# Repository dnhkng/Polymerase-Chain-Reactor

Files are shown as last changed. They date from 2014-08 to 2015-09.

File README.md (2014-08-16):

Polymerase-Chain-Reactor
========================

An Open Source PCR machine for DIY Recombinant Genetics, and entry to the Hackaday Prize! If you like it, please Skull it at http://hackaday.io/project/1864-%245-Polymerase-Chain-Reactor

This project describes the designs for a remarkably simple but fully functional DNA replicator, based around the Arduino platform, and utilizing just a handful of components. The trick is to use multiple physical process driven by just heat! Heat drives DNA conversion between its single and double strand state; alters the activity of the polymerase to copy DNA; and drives circulation of the reaction medium via convection. So, it's all and heat and geometry, intead of trying to shift temperature as fast and accurately as possible with expensive hardware. 

It uses the Arduino libraries, and the Arduino PID Library by Brett Beauregard.

Eagle schematics and a boards layout files are also included.

The project is GPLv3 licenced

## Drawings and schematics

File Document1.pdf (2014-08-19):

# $5 PCR Machine

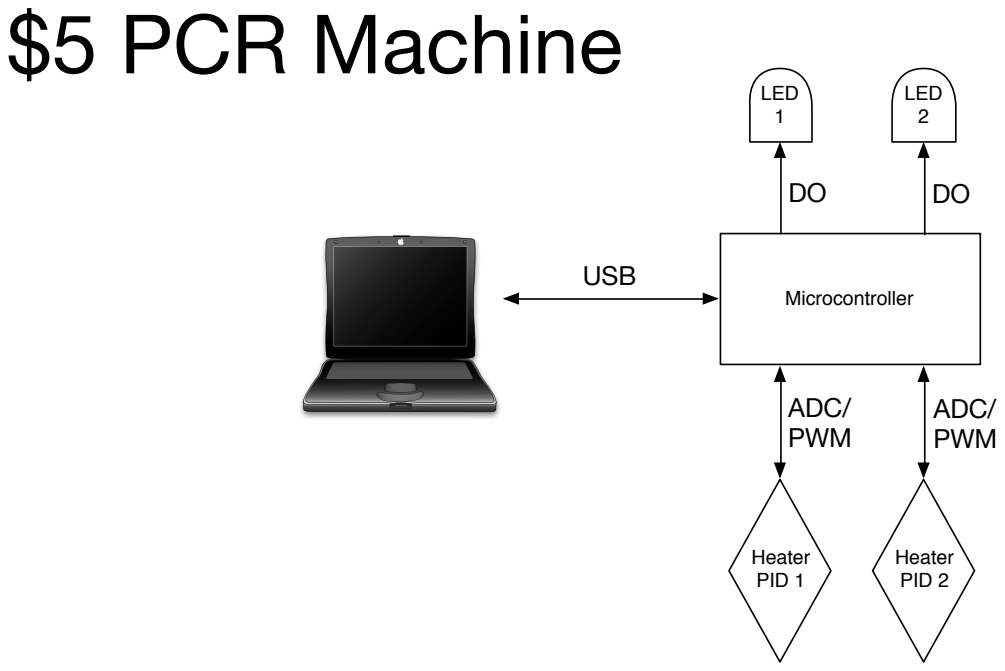
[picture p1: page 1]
Microcontroller; USB; Heater PID 1; Heater PID 2; LED 1; LED 2; ADC/ PWM

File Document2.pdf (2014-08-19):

## CLOUD

# $50 PCR Machine

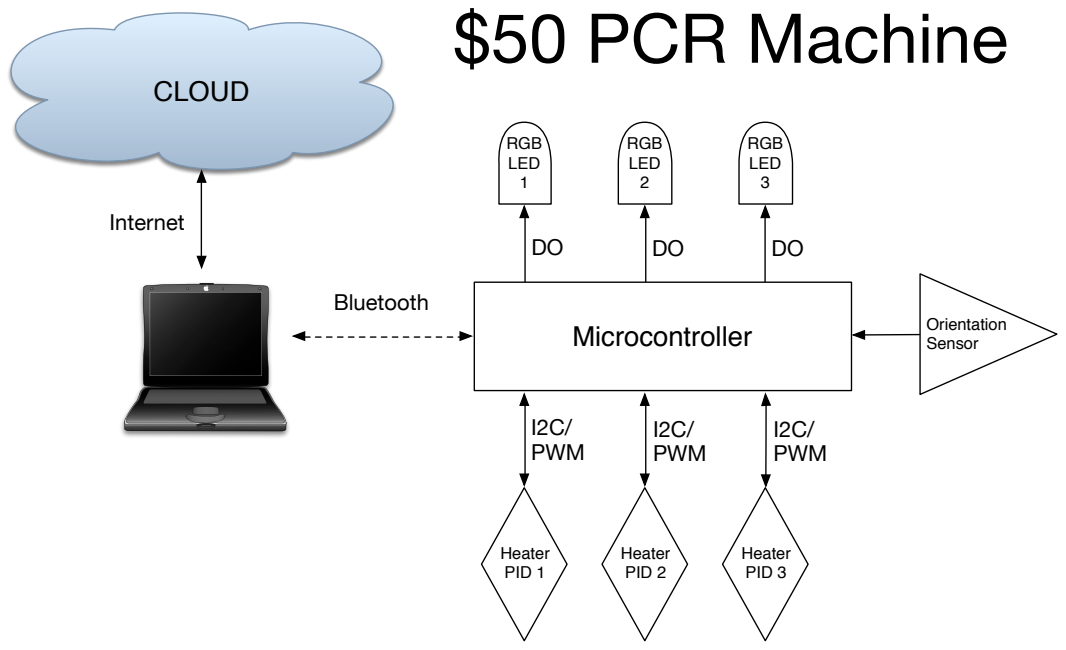
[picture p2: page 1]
Microcontroller; Bluetooth; Internet; Heater PID 1; Heater PID 2; RGB LED 1; I2C/ PWM; Heater PID 3; Orientation Sensor; RGB LED 2; RGB LED 3

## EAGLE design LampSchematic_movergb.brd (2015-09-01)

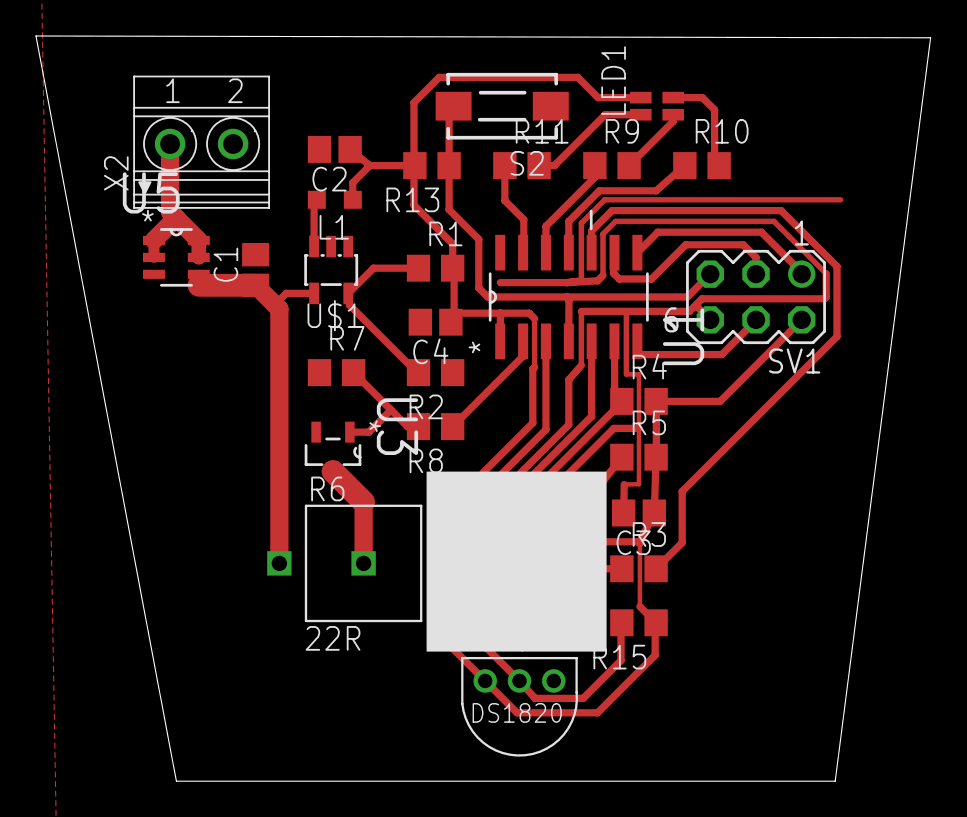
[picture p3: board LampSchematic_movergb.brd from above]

Board: 2 copper layers, 49.7 x 41.4 mm, 29 parts (0 on the bottom side), 24 nets.

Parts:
C1, C3, C4: 0.1uF; C0805
C2: 10uF; C0805
L1: 10uH; L2012C
LED1: GM1WA55311A
R1: 61.9k; R0805
R2: 20k; R0805
R3, R15: 6.8R; R0805
R4, R5: 4.7k; R0805
R6: 22R; 5WRESISTOR
R7: 100k; R0805
R8: 47R; R0805
R9: 330R; R0805
R10, R11: 68R; R0805
R13: 10k; R0805
S2: DTSM-3
SV1: ISP; MA03-2
U1: ATTINY84-20SSU; SOIC127P600X175-14N
U2: VEML6040
U3: PMV20ENR; SOT95P230X110-3N
U5: Si3417DV; SOP95P285X110-6N
U$1: TPS560200; SOT23-5L
U$2: DS1820TO92; DS1820
U$3: UV; GM5BW96385A
X2: 1751248

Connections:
+12V: C1.1, R6.P$2, U5.4, U$1.4
BLUE: R11.1, U1.13
GND: C1.2, C2.2, C3.2, C4.2, R2.1, R7.1, S2.1, SV1.6, U1.14, U2.1, U3.2, U5.3, U$1.2, U$2.GND, U$3.2, X2.2
GREEN: R10.1, U1.11
HEAT: R8.1, U1.2
MISO: SV1.1, U1.8
MOSI: SV1.4, U1.7
unnamed: L1.2, U$1.3
unnamed: R1.1, R2.2, U$1.5
unnamed: R6.P$1, U3.3
unnamed: R7.2, R8.2, U3.1
unnamed: LED1.2, R9.2
unnamed: LED1.3, R10.2
unnamed: LED1.1, R11.2
unnamed: R3.1, U$3.1
unnamed: U5.1, U5.2, U5.5, U5.6, X2.1
RED: R9.1, U1.12
RES: R13.1, S2.2, SV1.5, U1.4
SCK: SV1.3, U1.9
SCLK: R5.1, U1.5, U2.3
SDAT: R4.1, U1.6, U2.2
TEMP: R15.2, U1.3, U$2.DQ
UV: R3.2, U1.10
VCC: C2.1, C3.1, C4.1, L1.1, LED1.4, R1.2, R4.2, R5.2, R13.2, R15.1, SV1.2, U1.1, U2.4, U$2.VDD

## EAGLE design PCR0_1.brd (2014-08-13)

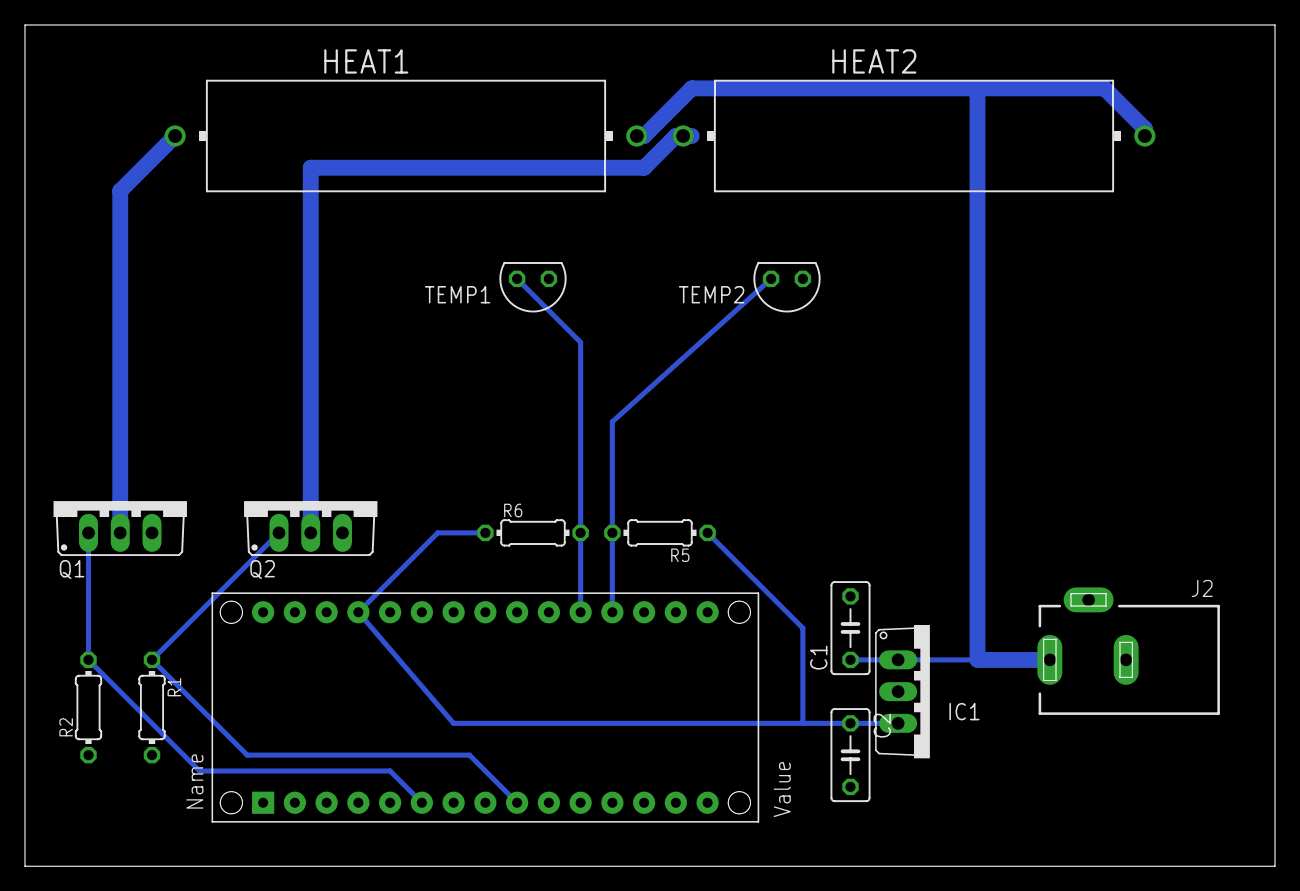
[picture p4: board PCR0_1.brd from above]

Board: 2 copper layers, 100.0 x 67.3 mm, 15 parts (0 on the bottom side), 9 nets.

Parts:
C1, C2: C050-030X075
HEAT1, HEAT2: 10; HPS932
IC1: 7805TV; TO220V
J2: DCJ0303
Q1, Q2: IRF740; TO220BV
R1, R2: 10K; 0204/7
R5, R6: 2K; 0204/7
TEMP1, TEMP2: LM335; TO92H
U$1: PDIP-32

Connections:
+5V: C2.1, IC1.3, R5.1, R6.1, U$1.+5V
GND: C1.2, C2.2, IC1.2, J2.2, J2.3, Q1.S, Q2.S, R1.2, R2.1, TEMP1.1, TEMP2.1, U$1.GND, U$1.GND1
H1: Q1.G, R2.2, U$1.D3
H2: Q2.G, R1.1, U$1.D6
unnamed: HEAT1.1, Q1.D
unnamed: HEAT2.1, Q2.D
T1: R6.2, TEMP1.2, U$1.A6
T2: R5.2, TEMP2.2, U$1.A7
V+: C1.1, HEAT1.2, HEAT2.2, IC1.1, J2.1

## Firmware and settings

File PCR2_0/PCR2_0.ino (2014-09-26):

#include <Wire.h>
#include <PID_v1.h>
#include <SerialCommand.h>

SerialCommand sCmd; 

int SensorA = 0b0011001; // Denaturation
int SensorB = 0b0011010; // Annealing
int SensorC = 0b0011000; // Elongation

int TempReg = 0b00000101;

int HeaterPinA = 5; // Denaturaion
int HeaterPinB = 3; // Annealing
int HeaterPinC = 6; // Elongation

double TargetA = 1.0;
double TargetB = 1.0;
double TargetC = 1.0;

double InputA, InputB, InputC;
double OutputA, OutputB, OutputC;

double P = 100.0;
double I = 0.0;
double D = 0.0;

boolean stream = LOW;

PID HeaterA(&InputA, &OutputA, &TargetA, 100,0,0, DIRECT);
PID HeaterB(&InputB, &OutputB, &TargetB, 100,0,0, DIRECT);
PID HeaterC(&InputC, &OutputC, &TargetC, 100,0,0, DIRECT);

void setup() {
  Wire.begin();        // join i2c bus (address optional for master)
  Serial.begin(38400);
  
  pinMode(HeaterPinA, OUTPUT);
  pinMode(HeaterPinB, OUTPUT);
  pinMode(HeaterPinC, OUTPUT);
  
  HeaterA.SetMode(AUTOMATIC);
  HeaterB.SetMode(AUTOMATIC);
  HeaterC.SetMode(AUTOMATIC);
  
  HeaterA.SetTunings(P,I,D);
  HeaterB.SetTunings(P,I,D);
  HeaterC.SetTunings(P,I,D);
  
  // Setup callbacks for SerialCommand commands
  sCmd.addCommand("SETPID",   setPID);     // Set the PID values for a heating element
  sCmd.addCommand("SETTEMP",  setTEMP);    // Set the target temperature for a heating element
  sCmd.addCommand("GETPID",   getPID);     // Return the PID values for a heating element
  sCmd.addCommand("GETTARGET", getTARGET); // Return the temperature of a heating element  
  sCmd.addCommand("GETTEMP",  getTEMP);    // Return the temperature of a heating element
  sCmd.addCommand("STARTSTREAM",  streamSTART);  // turns on and off continuous temperature reporting
  sCmd.addCommand("STOPSTREAM",  streamSTOP);  // turns on and off continuous temperature reporting
  sCmd.addCommand("RESET",  resetTWI);  // turns on and off continuous temperature reporting
  sCmd.addCommand("OFF",  powerDown);      // turns off all heaters by setting target temp to zero
  sCmd.setDefaultHandler(unrecognized);    // Handler for command that isn't matched  (says "Unrecognized Command?")
  
  // Sets temperature sensors for measurement mode
  Wire.beginTransmission(SensorA); // transmit to I2C
  Wire.write(TempReg);              // sends one byte.   
  Wire.endTransmission();    // stop transmitting
  Wire.beginTransmission(SensorB); // transmit to I2C
  Wire.write(TempReg);              // sends one byte.   
  Wire.endTransmission();    // stop transmitting
  Wire.beginTransmission(SensorC); // transmit to I2C
  Wire.write(TempReg);              // sends one byte.   
  Wire.endTransmission();    // stop transmitting
  
  Serial.println("PCR Device Ready");
}


float temperature(int I2C_address) {
  Wire.requestFrom(I2C_address, 2);    // request 2 bytes from address. Because sensor produces 9 bit
  int ambientUpper = 0;
  int ambientLower = 0;
  
  while(Wire.available()) {   // slave may send less than requested
    ambientUpper = Wire.read(); // receive a byte as integer
    ambientLower = Wire.read(); // receive a byte as integer Can change resolution of by chaning 2nd and 3rd bit of the register pointers.
  }  
  
  int a = ambientUpper << 6; // bitshift 6 to the left to allow for 9bit data from temp sensor
  int b = ambientLower >> 2; //bitshift 7 to the right to allow for 9 bit data from temp sensor.
  int tempRaw = a|b;  // define int rawtemp as the combination of integer a and b. We now have 9 bits of data. 
  float dec = 0.0;
  float power = 0.25;
  int mask; 
  int weight;
  
  for (mask = 1; mask<256; mask <<= 1) {
    if (tempRaw & mask) {
      weight = 1;     
    }
    else {
      weight = 0;     
    }  
    dec = dec + (power * weight);
    power = power * 2; 
 }
  return dec;
}  


void setPID() {
  char *arg;
  float p;
  float i;
  float d;
  boolean malformed = LOW;

  arg = sCmd.next();
  if (arg != NULL) {
    if (atof(arg) > 0 && atof(arg) < 300) {
      p = atof(arg);
    }
    else {
      malformed = HIGH;
    }  
  }    
  else {
    malformed = HIGH;
  } 
  
  arg = sCmd.next();
  if (arg != NULL) {
    if (atof(arg) > 0 && atof(arg) < 300) {
      i = atof(arg);
    }
    else {
      malformed = HIGH;
    }
  }      
  else {
    malformed = HIGH;
  } 
  
  arg = sCmd.next();
  if (arg != NULL) {
    if (atof(arg) > 0 && atof(arg) < 300) {
      d = atof(arg);
    }
    else {
      malformed = HIGH;
    }  
  }  
  else {
    malformed = HIGH;
  }  
  
  arg = sCmd.next();
  if (arg != NULL) {
    malformed = HIGH;
  }  
  
  if (!malformed) {
    HeaterA.SetTunings(p,i,d);
    HeaterB.SetTunings(p,i,d);
    HeaterC.SetTunings(p,i,d);
    Serial.print("PID Values: ");
    Serial.print(p);
    Serial.print(", ");
    Serial.print(i);
    Serial.print(", ");
    Serial.println(d);
  }
  else {
    Serial.println("Unrecognized Command");
  }  
}

void setTEMP() {
  char *arg;
  float tempA;
  float tempB;
  float tempC;
  boolean malformed = LOW;
  

  arg = sCmd.next();
  if (arg != NULL) {
    if (atof(arg) > 0 && atof(arg) < 100) {
      tempA = atof(arg);
    }
    else {
      malformed = HIGH;
    }  
  }    
  else {
    malformed = HIGH;
  } 
  
  arg = sCmd.next();
  if (arg != NULL) {
    if (atof(arg) > 0 && atof(arg) < 100) {
      tempB = atof(arg);
    }
    else {
      malformed = HIGH;
    }  
  }    
  else {
    malformed = HIGH;
  } 
  
  arg = sCmd.next();
  if (arg != NULL) {
    if (atof(arg) > 0 && atof(arg) < 100) {
      tempC = atof(arg);
    }
    else {
      malformed = HIGH;
    }  
  }    
  else {
    malformed = HIGH;
  }   
  
  arg = sCmd.next();
  if (arg != NULL) {
    malformed = HIGH;
  }  
  
  if (!malformed) {
    TargetA = tempA;
    TargetB = tempB;
    TargetC = tempC;
    Serial.print("Temperature Target Values: ");
    Serial.print(TargetA);
    Serial.print(", B:");
    Serial.print(TargetB);
    Serial.print(", C:");
    Serial.println(TargetC);
  }
  else {
    Serial.println("Unrecognized Command");
  }  
}


void getPID() {
  Serial.print("PID Values: P:");
  Serial.print(HeaterA.GetKp());
  Serial.print(", I:");
  Serial.print(HeaterA.GetKi());
  Serial.print(", D:");
  Serial.println(HeaterA.GetKd());
}


void getTARGET() {
  Serial.print("Temperature Target Values: A:");
  Serial.print(TargetA);
  Serial.print(", B:");
  Serial.print(TargetB);
  Serial.print(", C:");
  Serial.println(TargetC);
}

void getTEMP() {
  float tempA = temperature(SensorA);
  float tempB = temperature(SensorB);
  float tempC = temperature(SensorC);
  Serial.print("Temperature Values: A:");  
  Serial.print(tempA);
  Serial.print(", B:");
  Serial.print(tempB);
  Serial.print(", C:");
  Serial.println(tempC);

}  

void streamSTART() {
  stream = HIGH;
  Serial.println("Stream Started");
}

void streamSTOP() {
  stream = LOW;
  Serial.println("Stream Stopped");
}


void powerDown() {
  TargetA = 1.0;
  TargetB = 1.0;
  TargetC = 1.0;
  Serial.print("TEMP Targets: A:");
  Serial.print(TargetA);
  Serial.print(", B:");
  Serial.print(TargetB);
  Serial.print(", C:");
  Serial.println(TargetC);
}  


void resetTWI() {
  // Sets temperature sensors for measurement mode
  Wire.beginTransmission(SensorA); // transmit to I2C
  Wire.write(TempReg);              // sends one byte.   
  Wire.endTransmission();    // stop transmitting
  Wire.beginTransmission(SensorB); // transmit to I2C
  Wire.write(TempReg);              // sends one byte.   
  Wire.endTransmission();    // stop transmitting
  Wire.beginTransmission(SensorC); // transmit to I2C
  Wire.write(TempReg);              // sends one byte.   
  Wire.endTransmission();    // stop transmitting
  Serial.print("TWI Temperature Sensors Reset");
}  
  
void unrecognized(const char *command) {
  Serial.println("Unrecognized Command");
}

void loop() {
  sCmd.readSerial(); 

  InputA = temperature(SensorA);
  HeaterA.Compute();
  analogWrite(HeaterPinA,OutputA);
  
  InputB = temperature(SensorB);
  HeaterB.Compute();
  analogWrite(HeaterPinB,OutputB);  
  
  InputC = temperature(SensorC);
  HeaterC.Compute();
  analogWrite(HeaterPinC,OutputC);  

  if (stream){
    Serial.print("DATA ");
    Serial.print(InputA);
    Serial.print(' ');
    Serial.print(InputB);
    Serial.print(' ');
    Serial.print(InputC);
    Serial.print(' ');
    Serial.print(OutputA);
    Serial.print(' ');
    Serial.print(OutputB);
    Serial.print(' ');
    Serial.println(OutputC); 
  }
  
  delay(500);
}

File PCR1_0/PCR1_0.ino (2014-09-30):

/********************************************************
 * Polymerase Chair Reactor v0.2.1
 * This Library is licensed under a GPLv3 License
 * Uses the Arduino Nano
 * Requires the Arduino PID Library by Brett Beauregard
 ********************************************************/

#include <PID_v1.h>
#include <HIDSerial.h>

HIDSerial serial;

//Define Variables we'll be connecting to
double Setpoint1 = 95;
double Setpoint2 = 72;
double Input1, Output1, Input2, Output2;
float ADC1 = 0, ADC2 = 0, temp1 = 0, temp2=0;
unsigned long serialTime;
int led = 0, Probe1 = 1, Probe2 = 0, PWM1 = 6, PWM2 = 5;
boolean state = LOW;

//Specify the links and initial tuning parameters
PID myPID1(&Input1, &Output1, &Setpoint1, 80,0,0, DIRECT);
PID myPID2(&Input2, &Output2, &Setpoint2, 80,0,0, DIRECT);

void setup()
{
  //initialize the variables we're linked to
  pinMode(PWM1, OUTPUT);
  pinMode(PWM2, OUTPUT);
  pinMode(led, OUTPUT);
  digitalWrite(led, HIGH); 

  ADC1 = analogRead(Probe1);
  ADC2 = analogRead(Probe2);  

  serial.begin();
  //turn the PID on
  myPID1.SetMode(AUTOMATIC);
  myPID2.SetMode(AUTOMATIC);
}

void loop()
{
  serial.poll();
  
  
  ADC1 = analogRead(Probe1);
  ADC2 = analogRead(Probe2);
  

  temp1 = ADC1 * -0.3059 + 198.39; //Calculate these contants from a linear fit with a thermometer
  temp2 = ADC2 * -0.3059 + 198.39;
  
  Input1 = temp1;
  Input2 = temp2;
  
  myPID1.Compute();
  myPID2.Compute();
  
  analogWrite(PWM1,Output1);
  analogWrite(PWM2,Output2);
  
  if(millis()>serialTime)
  {
    //SerialReceive();
    SerialSend();
    //serial.println("Hello World!");
    //serial.println(raw);
    serialTime+=1000;
    
    if(state) {
      state = LOW;
      digitalWrite(led, LOW);
    }  
    else {
      state = HIGH;
      digitalWrite(led, HIGH);
    }
    delay(30); // reduces ADC interferrence
  }
 
}

void SerialSend()
{
  serial.print(ADC1);
  serial.print(" ");
  serial.print(ADC2);
  serial.print(" ");
  serial.print(temp1);
  serial.print(" ");  
  serial.print(temp2);
  serial.print(" ");
  serial.print(Output1);
  serial.print(" ");
  serial.println(Output2); 
}

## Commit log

2014-08-12 First Upload
    Arduino 1.0.5 code for the Polymerase Chain Reactor, and entry in the
    Hackaday Prize
2014-08-13 Schematics and PCB designs
    A simple single-sided board for the Arduino Nano based device.
    [v02.brd, v02.sch]
2014-09-26 The second, more sophisticated PCR machine
    Arduino code - Initial upload
2014-09-27 Name changes
    [PCR0_1.brd, PCR0_1.sch]
2015-08-31 LAMP project
    first commit of schematic and board
    [LampSchematic_movergb.brd, LampSchematic_movergb.sch]
2015-09-01 updates the LAMP stuff
    Better layout for the PCB
    [LampSchematic_movergb.brd, LampSchematic_movergb.sch]
